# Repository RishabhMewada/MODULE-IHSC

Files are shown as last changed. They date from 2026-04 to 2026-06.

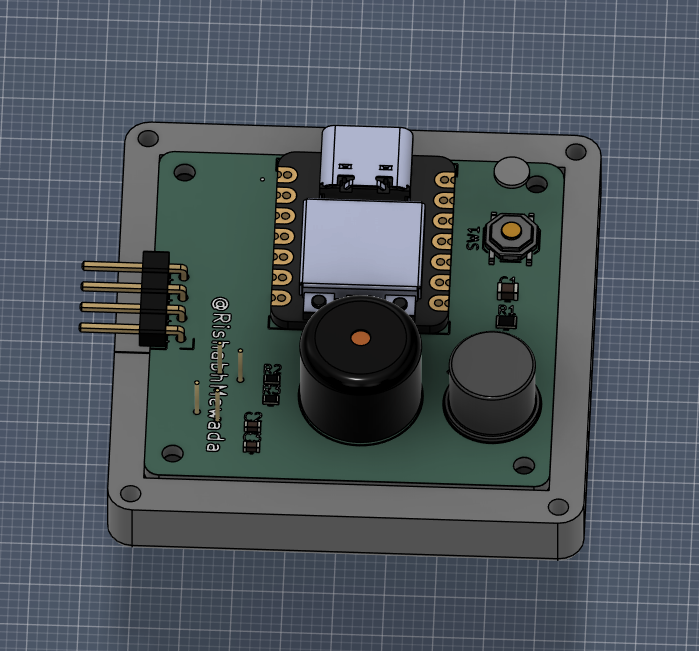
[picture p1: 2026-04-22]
Images/CAD-3.png

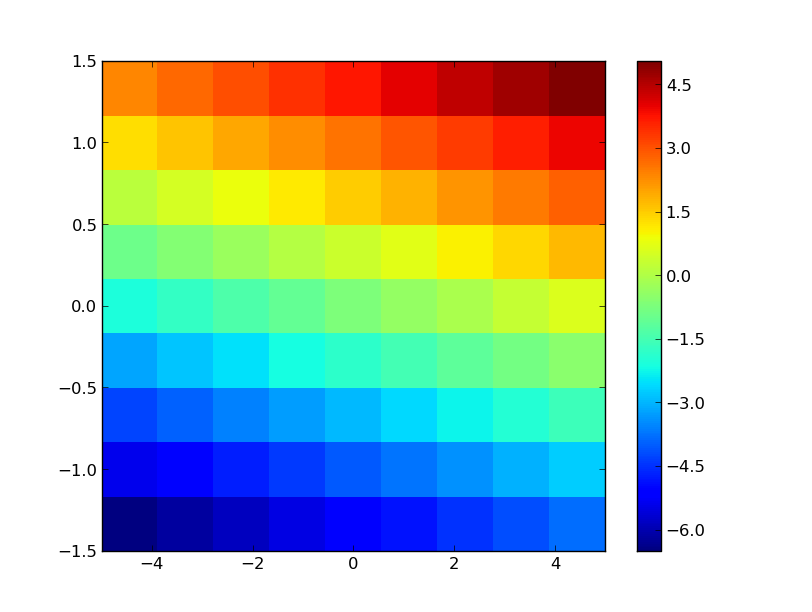
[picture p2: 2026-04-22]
Images/Rainbow heatmap.png

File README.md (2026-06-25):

# MODULE-IHSC
A thermal imaging module consisting of XIAO RP2040 &amp; MLX90640 for thermal camera and XIAO for the onboard processing 
which supports usb type c streaming and usb screen sharing extension via an 4 pin I2C extension

 <p align="center">
PCB-3D-FRONT
</p>

-------------------------------------------------------------------------------------------------
## Purpose 
The goal of this project was to design a low profile thermal camera module capable of streaming live
footage over to the screen via type c and I2C pins

things considerd in mind to make it happen
- PCB design
- CAD 
- Components
- Firmware modularization and easy modification
  
 <p align="center">
 Schematics
</p>

 <p align="center">

</p>

-------------------------------------------------------------------------------------------------
## Features

*Core Hardware*

- XIAO RP2040
- MLX90640  
- 4 Pin I2C horizontal pins 
- buzzer for beeping
- tactile switch
- transistor
 
-------------------------------------------------------------------------------------------------
## Transport & Connectivity

 - 4 Pin I2C horizontal pins 
- USB-C connection
-------------------------------------------------------------------------------------------------
## Hardware
The PCB is designed using KiCad (open-source) and the case using Fusion 360.

Specifications

- 2-layer PCB
- XIAO RP2040 Proccessing
- MLX90640  heat Camera
- I²C  4 pin connector
- 
All PCB source files are available in `/hardware/kicad`.

<p align="center">
  CAD-3
</p>

-------------------------------------------------------------------------------------------------

## Firmware

- Thermal Sensing camera

*Raw MLX90640 32×24 thermal array with 768 pixels, connected directly via I2C
with 110° wide field of view built into the camera
and have the abillity to measure −40 °C to +300 °C measurement range
Dual I2C bus architecture — sensor on I2C1 (GP6/GP7), display on I2C0 (GP4/GP5) to prevent bus conflicts*

- Rainbow Heatmap

*Full 7-stop rainbow colour mapping (violet → blue → cyan → green → yellow → orange → red)
Bicubic interpolation upscaling from 32×24 to full display resolution which will convert it into 
Real-time hotspot and coldspot crosshair overlays with temperature labels
Live temperature scale bar rendered on-screen*

<p align="center">
  Rainbow heatmap
</p>

- Dual Output System

*USB-CDC mode — binary frame stream over via a Type-C cable to a PC host viewer
I2C display mode — frames rendered directly onto an external OLED via the 4-pin PCB connector (SSD1306 128×64 or SH1107 128×128)
BOTH mode — simultaneous USB stream and I2C display output
Smart startup auto-detection: defaults to BOTH if display and USB host are both detected, I2C is used only if no PC is connected or USB if no display is found*

- Output Switching

*Short-press mode button cycles USB → I2C → BOTH → USB in real time
Long-press mode button saves current mode to flash (persists across reboots)
PC-side display_switch.py utility to switch modes remotely over USB without touching the device
Soft-reset trigger from PC so new mode activates immediately without unplugging* (made for future integration)

- PC Host Viewer (host_display.py)

*Live OpenCV window with rainbow heatmap whit support up to 30 fps
Bicubic interpolation for smooth upscaled display
Adjustable window scale factor
and it Cycle's through 5 colour maps: Rainbow, Inferno, Plasma, Bone, Jet
and the Temperature range lock/unlock (freeze min–max for consistent colour mapping)
and shows Hotspot and coldspot crosshairs with live °C labels and it has a 
Full-screen toggle
Live FPS counter and frame index overlay*

- PC Switch Utility (display_switch.py)

*Query current output mode from the device which 
Switchs to the output mode (USB / I2C / BOTH) via command line and
Scan the 4-pin I2C connector bus to detect connected display hardware and then
 the Live frame monitor — prints per-frame FPS, Tmin, Tmax, and checksum status and it also
Auto-detects RP2040 serial port (no --port flag needed in most cases)*

- Performance

*~30 fps live thermal stream at 32 Hz sensor refresh rate in the MLX90640 camera
-USB-CDC frame size: 1562 bytes per frame (~47 KB/s, well within USB bandwidth)
 and uses Binary framing protocol with magic header and checksum validation for data integrity
and Frame index tracking for dropped frame detection*

- Hardware Controls

*Power button (GP28): short press pauses/resumes streaming; long press enters light-sleep
Mode button (GP29): short press cycles output mode; long press saves mode to flash
Buzzer (GP27): distinct beep patterns for each event — power-on, mode switch (unique per mode), mode saved, sleep, and error*

- Buzzer Feedback

Single long beep on power-on
1 beep = USB mode selected
2 beeps = I2C display mode selected
3 beeps = BOTH mode / mode saved to flash
Double beep = entering sleep
5 rapid beeps = sensor not found (wiring error)

- Persistent Configuration

*Output mode saved to output_mode.json on the RP2040's onboard flash
Automatically restored on every reboot with no user intervention*

Firmware files are located in `/firmware`.

-------------------------------------------------------------------------------------------------
## Images

 <p align="center">
    PCB
</p>

 <p align="center">
    
</p>

<p align="center">
     
</p>

-------------------------------------------------------------------------------------------------
## BOM
The complete bill of materials (BOM), including purchase links, is available in  
`/hardware/bom.csv`.

Manufacturing & sourcing:
- PCB fabrication: **JLCPCB**
- Components (India): **Robu.in**
- Enclosure: Online 3D printing services (if needed)

  <p align="center">
   
</p>

## Bill of Materials

| Name | Quantity | Total Cost (USD) | Distributor | Link |
|---|---|---|---|---|
| PCB | 5 | $8.00 | JLCPCB | [Buy](https://cart.jlcpcb.com/shopcart/cart/) |
| Soldering Flux | 1 | $0.27 | Robu.in | [Buy](https://robu.in/product/noel-flux-soldering-paste-10g) |
| MLX90640 | 1 | $37.48 | Digikey.in | [Buy](https://www.digikey.in/en/products/detail/melexis-technologies-nv/MLX90640ESF-BAA-000-SP/8638465) |
| XIAO RP2040 | 1 | $6.41 | Robocraze.in | [Buy](https://robocraze.com/products/seeed-studio-xiao-rp2040-development-board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) |
| Buzzer (BZ1) | 1 | $0.15 | Robu.in | [Buy](https://robu.in/product/3v-active-electromagnetic-buzzer-pack-of-5) |
| 1×4 Pin Header (J1) | 1 | $0.14 | Robu.in | [Buy](https://robu.in/product/ds1022-22-1x10ruf1-a3-0-b6-0-c6-0-b-connfly-1x10-pin-2-54mm-pin-header-r-a-type-h2-0mm) |
| Low Profile Tactile Switch SMD | 1 | $0.11 | Robu.in | [Buy](https://robu.in/product/tsc008a1718a-bzcn-4x4x1-7mm-50ma-round-button-50gf-12v-smd-tactile-switches-rohs) |
| Resistor 4.7 kΩ 0603 (R2) | 2 | $0.11 | Robu.in | [Buy](https://robu.in/product/4-7k-ohm-1-4w-0603-surface-mount-chip-resistor-pack-of-100) |
| Resistor 1 kΩ 0805 (R1) | 1 | $0.11 | Robu.in | [Buy](https://robu.in/product/1k-ohm-1-4w-0805-surface-mount-chip-resistor-pack-of-10) |
| Capacitor 100 nF 0805 (C1) | 1 | $0.12 | Robu.in | [Buy](https://robu.in/product/cs2012x7r106m100nre-samwha-10v-10uf-x7r-%c2%b120-0805-multilayer-ceramic-capacitors-mlcc-smd-smt-rohs) |
| Capacitor 1 µF 0603 (C3) | 1 | $0.11 | Robu.in | [Buy](https://robu.in/product/1uf-1000nf-50v-capacitor-0603-smd-package-pack-of-20) |
| Capacitor 10 µF 0805 (C2) | 1 | $0.11 | Robu.in | [Buy](https://robu.in/product/100nf-0805-surface-mount-multilayer-ceramic-capacitor-pack-of-40) |
| 2N2219 Transistor | 1 | $ | link |
| **Total** | | **$77.81** | | |

please note that most of the parts are from indian suppliers !

*note there's also a transistor in the project (2N2219) but it's not available anywhere online for me that's why it's not included in the BOM with price and link

-------------------------------------------------------------------------------------------------
## License
This project is open-source hardware and software and is released under the **MIT License**.

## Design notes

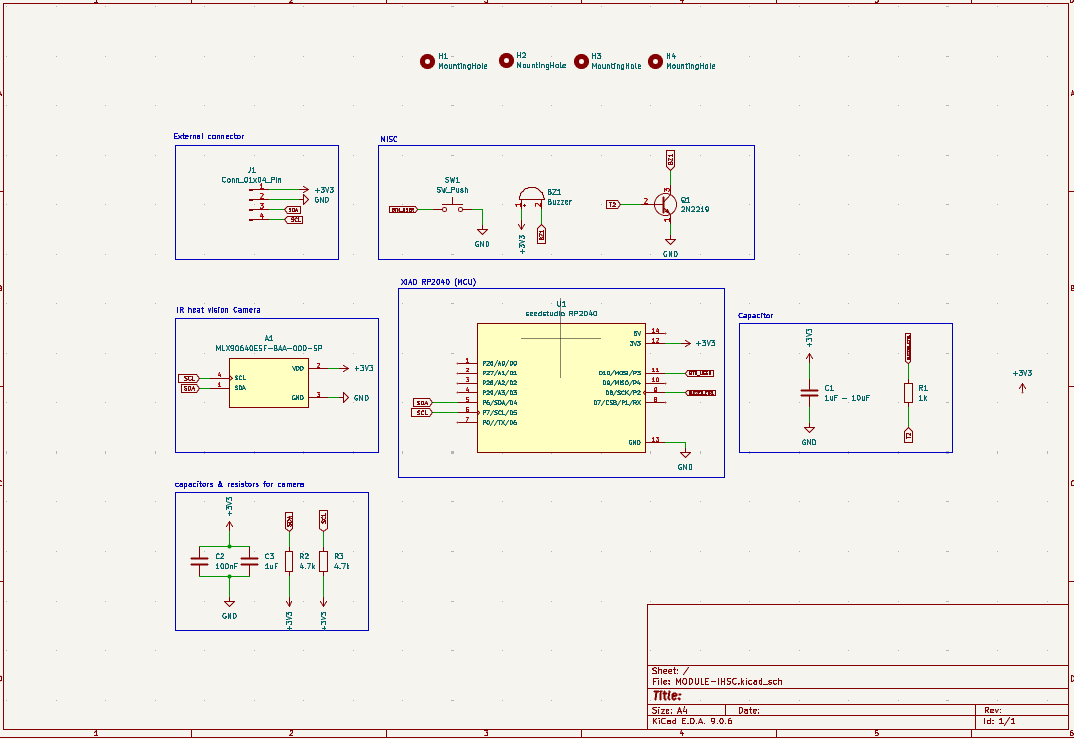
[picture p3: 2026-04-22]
Images/Schematics.png

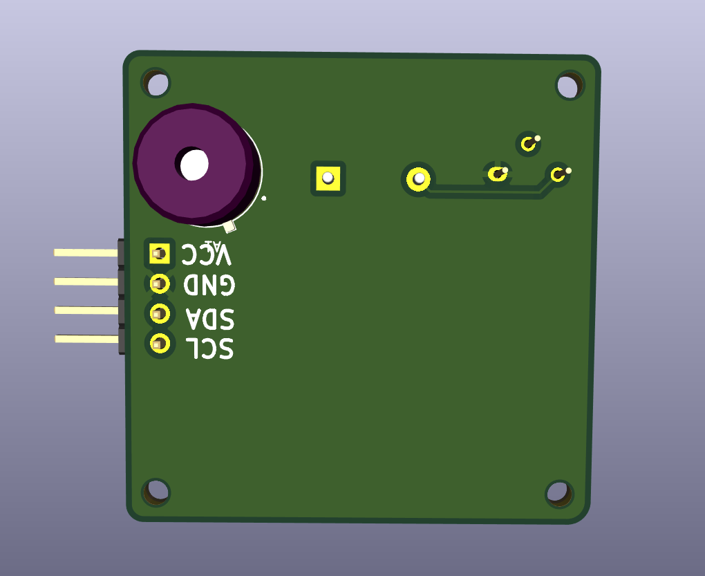
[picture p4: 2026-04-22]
Images/PCB-3D-BACK.png

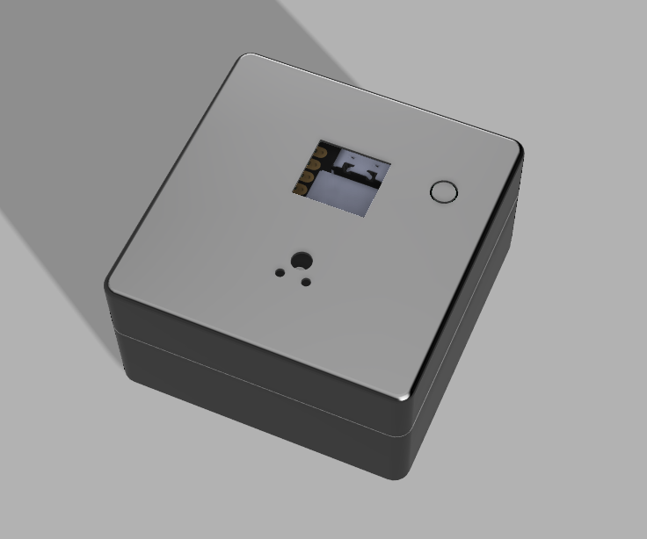
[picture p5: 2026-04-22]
Images/Render.png

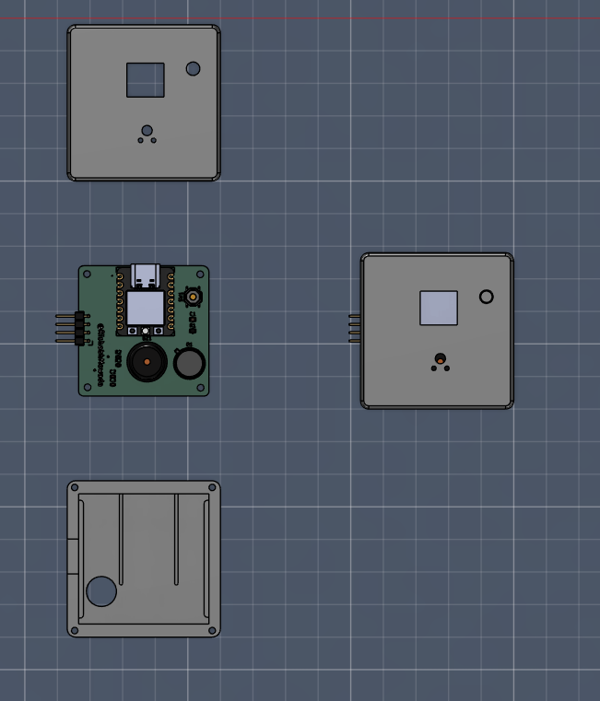
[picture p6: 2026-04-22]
Images/PCB-4.png

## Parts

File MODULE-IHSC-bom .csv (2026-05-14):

Name | Purpose | Quantity | Total Cost (USD) | Link | Distributor
hot air reflow gun | SMD | 1 | 23.98 | https://robu.in/product/yihua-8858-iv-portable-hot-air-station/ | Robu.in
PCB | pcb.its 8 dollars because i am also ordering pcb for my project side by side to reduce tax cost and shipping costs | 5 | 8.00 | https://cart.jlcpcb.com/shopcart/cart/ | JLPCB
soldering flux | flux | 1 | 0.27 | https://robu.in/product/noel-flux-soldering-paste-10g | Robu.in
MLX90640 | heat camera | 1 | 37.48 | https://www.digikey.in/en/products/detail/melexis-technologies-nv/MLX90640ESF-BAA-000-SP/8638465 | Digikey.in
XIAO RP2040 | MCU | 1 | 6.41 | https://robocraze.com/products/seeed-studio-xiao-rp2040-development-board?variant=47742255562976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 | Robocraze.in
Buzzer-BZ1 | beep beep. | 1 | 0.15 | https://robu.in/product/3v-active-electromagnetic-buzzer-pack-of-5 | Robu.in
1x4 pin header | would cut the 10 pin into 4 (J1) | 1 | 0.14 | https://robu.in/product/ds1022-22-1x10ruf1-a3-0-b6-0-c6-0-b-connfly-1x10-pin-2-54mm-pin-header-r-a-type-h2-0mm | Robu.in
low profile tactile switch SMD | switch. | 1 | 0.11 | https://robu.in/product/tsc008a1718a-bzcn-4x4x1-7mm-50ma-round-button-50gf-12v-smd-tactile-switches-rohs | Robu.in
Resistors | R2-4.7K Ohm | 2 | 0.11 | https://robu.in/product/4-7k-ohm-1-4w-0603-surface-mount-chip-resistor-pack-of-100 | Robu.in
Resistors | R1-1k Ohm | 1 | 0.11 | https://robu.in/product/1k-ohm-1-4w-0805-surface-mount-chip-resistor-pack-of-10 | Robu.in
capacitors | C1-100nF | 1 | 0.12 | https://robu.in/product/cs2012x7r106m100nre-samwha-10v-10uf-x7r-%c2%b120-0805-multilayer-ceramic-capacitors-mlcc-smd-smt-rohs | Robu.in
capacitors | C3-1uF | 1 | 0.11 | https://robu.in/product/1uf-1000nf-50v-capacitor-0603-smd-package-pack-of-20 | Robu.in
Capacitors | C2-10uF | 1 | 0.11 | https://robu.in/product/100nf-0805-surface-mount-multilayer-ceramic-capacitor-pack-of-40 | Robu.in

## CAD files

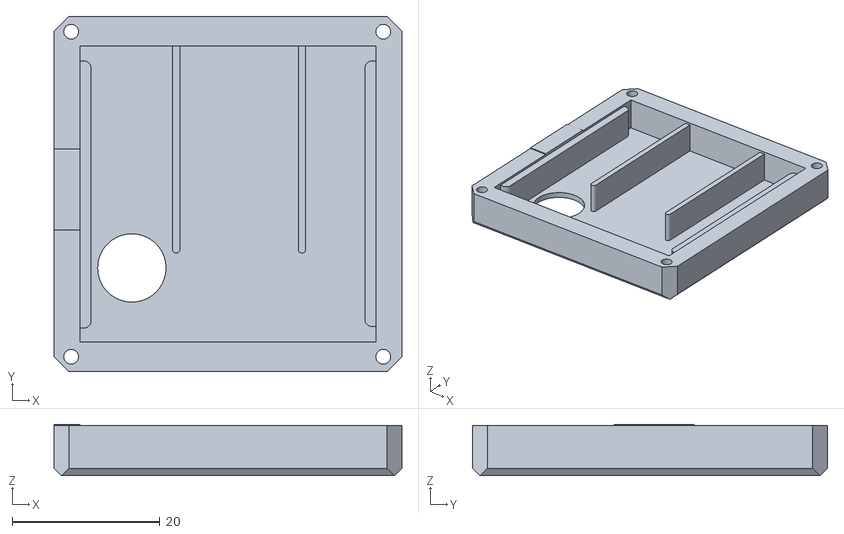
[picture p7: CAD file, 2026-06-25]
CAD MODELS/ IHSC-RD-BOTTOM-3DP.stl
47.0 x 48.0 x 6.94

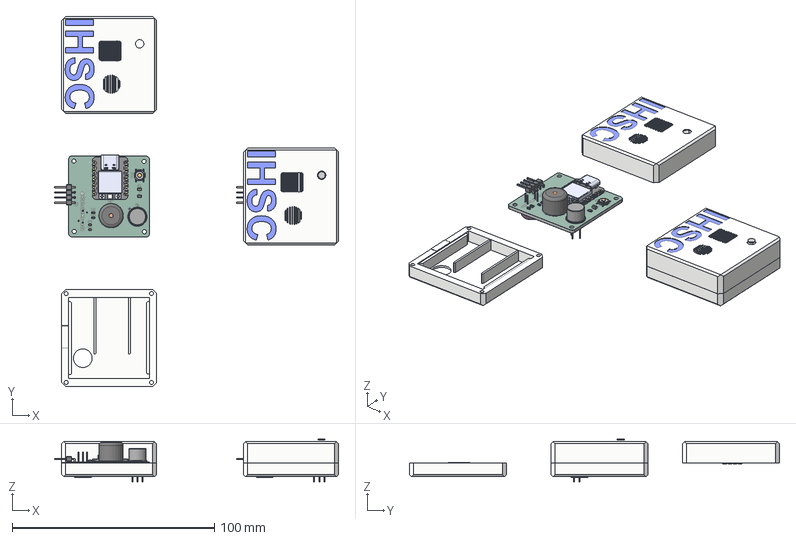
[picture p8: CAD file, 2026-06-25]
CAD MODELS/MODULE-IHSC-RD.step
140.5 x 183.0 x 21.1 mm
PinHeader_1x04_P2.54mm_Horizontal_1 x 2
C_0603_1608Metric x 4
C_0805_2012Metric x 2
R_0603_1608Metric x 4
PinHeader_1x04_P2.54mm_Horizontal x 2
R_0805_2012Metric x 2
TO-39-3 x 2
Buzzer_12x9.5RM7.6 x 2
SW_SPST_TL3342 x 2
MLX90640ESF-BAA-000-SP x 2
MODULE-IHSC_silkscreen x 2
MODULE-IHSC_silkscreen (1) x 2
MODULE-IHSC_soldermask x 2
MODULE-IHSC_soldermask (1) x 2
MODULE-IHSC_PCB x 2

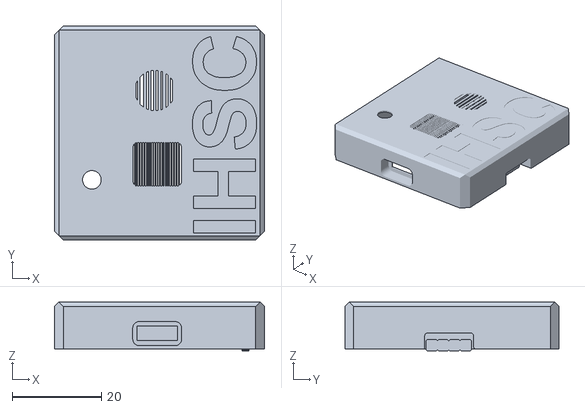
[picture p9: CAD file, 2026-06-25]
CAD MODELS/IHSC-RD-TOP-3DP.stl
47.0 x 48.0 x 11.0

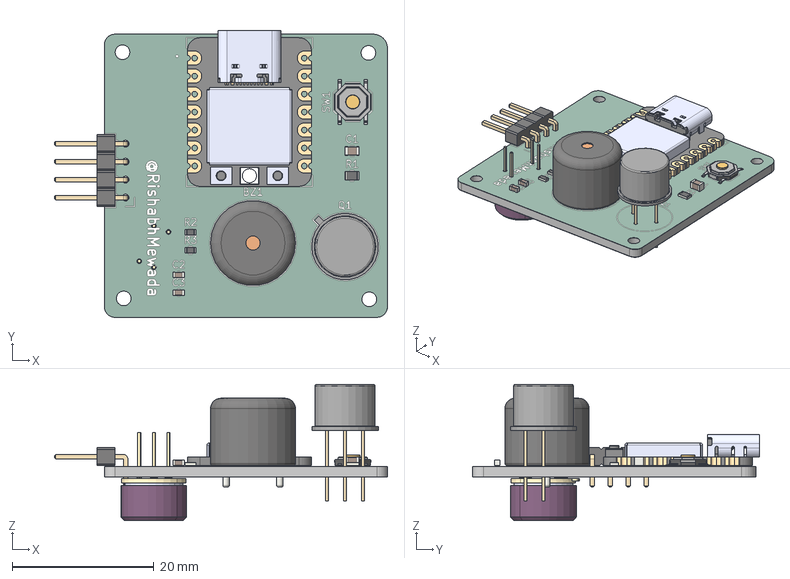
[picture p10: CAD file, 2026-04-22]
CAD MODELS/MODULE-IHSC.step
47.0 x 40.5 x 19.3 mm
C_0603_1608Metric x 2
C_0805_2012Metric
R_0603_1608Metric x 2
PinHeader_1x04_P2.54mm_Horizontal
R_0805_2012Metric
TO-39-3
Buzzer_12x9.5RM7.6
SW_SPST_TL3342
MLX90640ESF-BAA-000-SP
MODULE-IHSC_silkscreen x 2
MODULE-IHSC_soldermask x 2
MODULE-IHSC_PCB

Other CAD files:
CAD MODELS/MODULE-IHSC-RD.f3z
CAD MODELS/MODULE-IHSC-RD.stl

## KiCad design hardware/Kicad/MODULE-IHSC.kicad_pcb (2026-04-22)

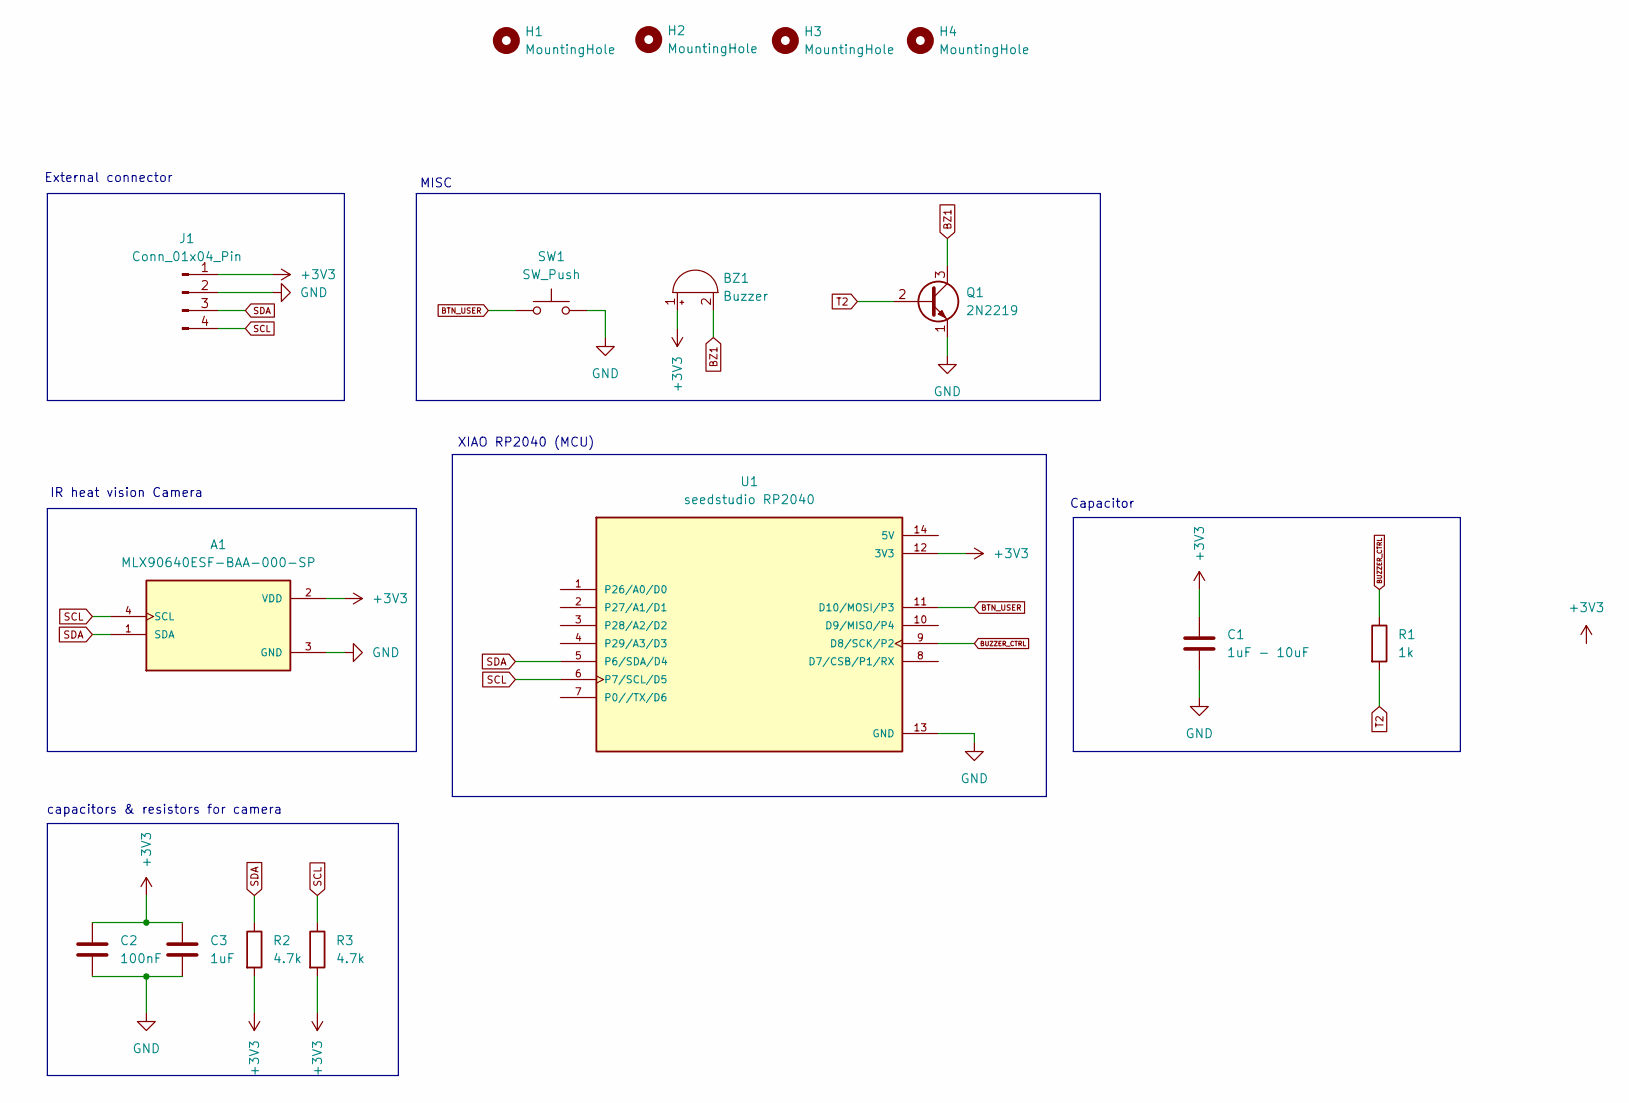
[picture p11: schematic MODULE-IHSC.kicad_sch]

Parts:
A1: MLX90640ESF-BAA-000-SP; TO292P930H600-4
BZ1: Buzzer; Buzzer_12x9.5RM7.6
C1: 1uF - 10uF; C_0805_2012Metric
C2: 100nF; C_0603_1608Metric
C3: 1uF; C_0603_1608Metric
H1, H2, H3, H4: MountingHole; MountingHole_2.1mm
J1: Conn_01x04_Pin; PinHeader_1x04_P2.54mm_Horizontal
Q1: 2N2219; TO-39-3
R1: 1k; R_0805_2012Metric
R2, R3: 4.7k; R_0603_1608Metric
SW1: SW_Push; SW_SPST_TL3342
U1: seedstudio RP2040; MODULE_102010428; DigiKey_Part_Number 1597-102010428-ND

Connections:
SCL: A1.4 (SCL), J1.4, R3.1, U1.6 (P7/SCL/D5)
+3V3: A1.2 (VDD), BZ1.1 (+), C1.1, C2.1, C3.1, J1.1, R2.2, R3.2, U1.12 (3V3)
BTN_USER: SW1.1, U1.11 (D10/MOSI/P3)
BUZZER_CTRL: R1.1, U1.9 (D8/SCK/P2)
BZ1: BZ1.2 (-), Q1.3 (C)
GND: A1.3 (GND), C1.2, C2.2, C3.2, J1.2, Q1.1 (E), SW1.2, U1.13 (GND)
SDA: A1.1 (SDA), J1.3, R2.1, U1.5 (P6/SDA/D4)
T2: Q1.2 (B), R1.2

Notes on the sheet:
MISC
XIAO RP2040 (MCU)
IR heat vision Camera
Capacitor
capacitors & resistors for camera
External connector

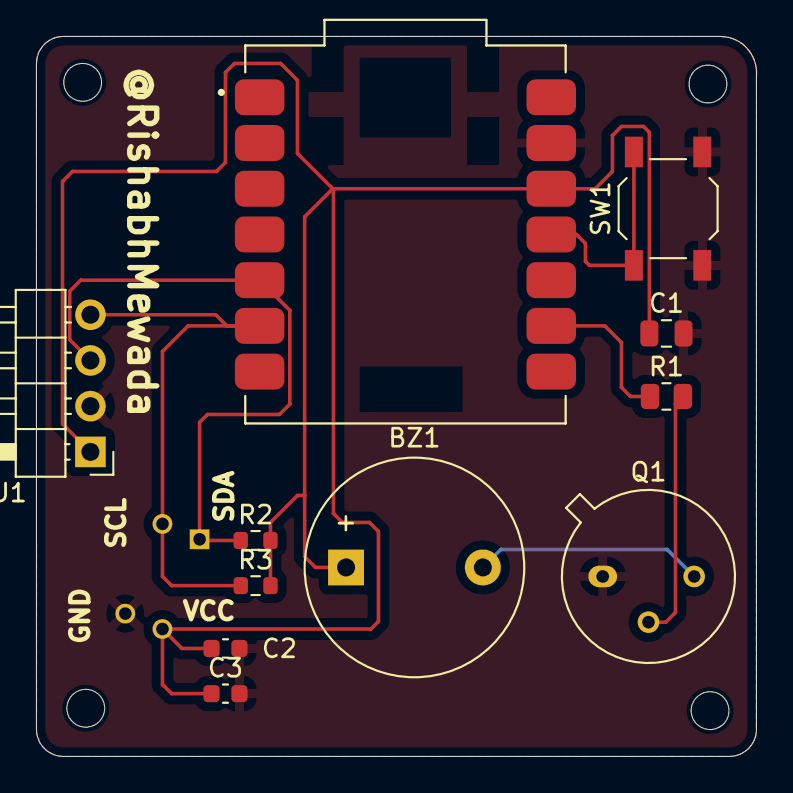
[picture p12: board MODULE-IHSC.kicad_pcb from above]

Board: 2 copper layers, 40.0 x 40.0 mm, 16 parts (1 on the bottom side), 8 nets.

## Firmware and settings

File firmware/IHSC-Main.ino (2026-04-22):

"""
=============================================================
  Thermal Camera — XIAO RP2040 + MLX90640 (110° FOV)
  Rainbow Heatmap  |  Dual Output  |  ~30 FPS
=============================================================

Hardware connections
--------------------
Raw MLX90640 chip (I2C1)  →  XIAO RP2040
  Pin 1 (VDD)  →  3V3
  Pin 2 (VSS)  →  GND
  Pin 3 (SDA)  →  GP6   (I2C1 SDA)
  Pin 4 (SCL)  →  GP7   (I2C1 SCL)

  REQUIRED external components (not on bare chip):
    4.7 kΩ resistor between GP6 (SDA) and 3V3  ← I2C pull-up
    4.7 kΩ resistor between GP7 (SCL) and 3V3  ← I2C pull-up
    100 nF ceramic capacitor between VDD and GND (place right at chip pins)

Buzzer    →  GP27  + GND  (active-high by default)
Power btn →  GP28  + GND  (internal pull-up)
Mode btn  →  GP29  + GND  (internal pull-up)

4-pin PCB output connector (I2C0 — second I2C bus)
----------------------------------------------------
  Pin 1  →  3V3          (power for external display)
  Pin 2  →  GND          (common ground)
  Pin 3  →  GP4  (SDA0)  (I2C data  → external display SDA)
  Pin 4  →  GP5  (SCL0)  (I2C clock → external display SCL)

  The RP2040 acts as I2C0 MASTER on this bus.
  The external display (e.g. SSD1306 OLED, SH1107, ST7789 via I2C)
  is the SLAVE. Frames are written to the display controller directly.

  Supported external display types (set EXT_DISPLAY_TYPE below):
    "SSD1306"  — 128×64 monochrome OLED  (I2C addr 0x3C or 0x3D)
    "SH1107"   — 128×128 monochrome OLED (I2C addr 0x3C)
    "NONE"     — 4-pin connector active but no rendering (raw I2C)

Output modes
------------
  MODE_USB  (0) : frames streamed over USB-CDC (Type-C → PC host_display.py)
  MODE_I2C  (1) : frames rendered on external I2C display (4-pin connector)
  MODE_BOTH (2) : USB-CDC stream AND I2C display simultaneously

Mode switching
--------------
  Short-press MODE_BTN  → cycle  USB → I2C → BOTH → USB …
  Long-press  MODE_BTN  → save current mode to flash (survives reboot)
  Short-press POWER_BTN → toggle streaming on/off
  Long-press  POWER_BTN → enter light-sleep (low power)

Startup mode priority
---------------------
  1. Saved mode in flash (output_mode.json) — if previously saved
  2. I2C display mode if an I2C display is detected on the 4-pin bus
  3. USB-CDC mode if a PC host is connected
  4. I2C mode as fallback (standalone use)

Buzzer feedback
---------------
  Power-on           : 1 long beep (200 ms)
  USB mode           : 1 medium beep
  I2C display mode   : 2 short beeps
  BOTH mode          : 3 short beeps
  Mode saved         : 3 short beeps
  Long-press sleep   : double beep
  No sensor error    : 5 rapid beeps

Protocol (USB-CDC binary, little-endian)
-----------------------------------------
  Offset  Size  Type      Field
  ------  ----  --------  --------------------------------
  0       4     uint32    Magic : 0xDEADBEEF
  4       2     uint16    Width  = 32
  6       2     uint16    Height = 24
  8       4     uint32    Frame index
  12      1     uint8     Output mode (0=USB 1=I2C 2=BOTH)
  13      3     uint8[3]  Reserved = 0x000000
  16      4     int32     T_min milli-°C
  20      4     int32     T_max milli-°C
  24      1536  uint16[]  Pixels: value = (T_°C + 40) × 100
  1560    2     uint16    Checksum (sum of pixel bytes & 0xFFFF)

Total = 1562 bytes per frame
=============================================================
"""

import time
import struct
import sys
import ustruct
import machine
import json
from machine import I2C, Pin

# ──────────────────────────────────────────────
#  Pin configuration
# ──────────────────────────────────────────────
# MLX90640 — I2C bus 1
I2C1_SDA_PIN = 6
I2C1_SCL_PIN = 7
I2C1_FREQ    = 400_000        # 400 kHz

# External display — I2C bus 0 (4-pin PCB connector)
I2C0_SDA_PIN = 4              # Pin 3 on connector
I2C0_SCL_PIN = 5              # Pin 4 on connector
I2C0_FREQ    = 400_000        # 400 kHz (reduce to 100_000 for long wires)

BUZZER_PIN         = 27
BUZZER_ACTIVE_HIGH = True

POWER_BTN_PIN = 28
MODE_BTN_PIN  = 29

# External display type — set to match your hardware
# Options: "SSD1306"  "SH1107"  "NONE"
EXT_DISPLAY_TYPE = "SSD1306"

# I2C addresses to scan for on the 4-pin bus
DISPLAY_ADDRS = {
    "SSD1306": [0x3C, 0x3D],
    "SH1107":  [0x3C, 0x3D],
    "NONE":    [],
}

# ──────────────────────────────────────────────
#  MLX90640
# ──────────────────────────────────────────────
MLX_ADDR     = 0x33
FRAME_WIDTH  = 32
FRAME_HEIGHT = 24
N_PIXELS     = FRAME_WIDTH * FRAME_HEIGHT
MLX_RATE_REG = 0b111          # 32 Hz

# ──────────────────────────────────────────────
#  Output modes
# ──────────────────────────────────────────────
MODE_USB  = 0
MODE_I2C  = 1
MODE_BOTH = 2
MODE_NAMES = {
    MODE_USB:  "USB-CDC",
    MODE_I2C:  "I2C-DISPLAY",
    MODE_BOTH: "BOTH",
}

CONFIG_FILE = "output_mode.json"

# ──────────────────────────────────────────────
#  Protocol (USB-CDC)
# ──────────────────────────────────────────────
MAGIC       = 0xDEADBEEF
HEADER_FMT  = "<IHHIBxxxii"
HEADER_SIZE = struct.calcsize(HEADER_FMT)   # 24 bytes
PIXEL_BYTES = N_PIXELS * 2                  # 1536 bytes
FRAME_SIZE  = HEADER_SIZE + PIXEL_BYTES + 2 # 1562 bytes


# ══════════════════════════════════════════════
#  Rainbow colour mapping  (7 colour stops)
#  Maps 0.0–1.0 → (R, G, B) 0–255
# ══════════════════════════════════════════════
# Colour stops: violet → blue → cyan → green → yellow → orange → red
_RAINBOW = [
    (0.00, (148,   0, 211)),   # violet
    (0.17, (  0,   0, 255)),   # blue
    (0.33, (  0, 255, 255)),   # cyan
    (0.50, (  0, 255,   0)),   # green
    (0.67, (255, 255,   0)),   # yellow
    (0.83, (255, 165,   0)),   # orange
    (1.00, (255,   0,   0)),   # red
]

def rainbow_rgb(t):
    """t in [0.0, 1.0] → (r, g, b) tuple 0-255."""
    t = max(0.0, min(1.0, t))
    for i in range(len(_RAINBOW) - 1):
        t0, c0 = _RAINBOW[i]
        t1, c1 = _RAINBOW[i + 1]
        if t0 <= t <= t1:
            f = (t - t0) / (t1 - t0)
            return (
                int(c0[0] + f * (c1[0] - c0[0])),
                int(c0[1] + f * (c1[1] - c0[1])),
                int(c0[2] + f * (c1[2] - c0[2])),
            )
    return _RAINBOW[-1][1]

def rainbow_gray(t):
    """Convert rainbow RGB → 8-bit grey (for monochrome displays)."""
    r, g, b = rainbow_rgb(t)
    return (r * 299 + g * 587 + b * 114) // 1000


# ══════════════════════════════════════════════
#  Flash config helpers
# ══════════════════════════════════════════════
def load_saved_mode():
    try:
        with open(CONFIG_FILE, "r") as f:
            cfg = json.load(f)
        m = int(cfg.get("mode", -1))
        if m in (MODE_USB, MODE_I2C, MODE_BOTH):
            print(f"[CFG] Loaded saved mode: {MODE_NAMES[m]}")
            return m
    except Exception:
        pass
    return None


def save_mode_to_flash(mode):
    try:
        with open(CONFIG_FILE, "w") as f:
            json.dump({"mode": mode}, f)
        print(f"[CFG] Mode saved: {MODE_NAMES[mode]}")
    except Exception as e:
        print(f"[CFG] Save failed: {e}")


# ══════════════════════════════════════════════
#  USB presence check
# ══════════════════════════════════════════════
def usb_enumerated():
    try:
        sys.stdout.buffer.write(b"")
        return True
    except Exception:
        return False


# ══════════════════════════════════════════════
#  MLX90640 driver
# ══════════════════════════════════════════════
class MLX90640:
    _REG_STATUS  = 0x8000
    _REG_CTRL1   = 0x800D
    _RAM_BASE    = 0x0400
    _EEPROM_BASE = 0x2400

    def __init__(self, i2c, addr=MLX_ADDR):
        self.i2c     = i2c
        self.addr    = addr
        self._buf2   = bytearray(2)
        self._eeprom = None
        self._params = {}
        self._load_eeprom()
        self._extract_params()
        self._set_refresh_rate(MLX_RATE_REG)

    def _read_reg(self, reg, n_words):
        self._buf2[0] = reg >> 8
        self._buf2[1] = reg & 0xFF
        self.i2c.writeto(self.addr, self._buf2)
        raw = self.i2c.readfrom(self.addr, n_words * 2)
        return [ustruct.unpack_from(">H", raw, i * 2)[0] for i in range(n_words)]

    def _write_reg(self, reg, value):
        buf = bytearray(4)
        buf[0] = reg >> 8;   buf[1] = reg & 0xFF
        buf[2] = value >> 8; buf[3] = value & 0xFF
        self.i2c.writeto(self.addr, buf)

    def _load_eeprom(self):
        self._eeprom = self._read_reg(self._EEPROM_BASE, 832)

    def _set_refresh_rate(self, rate_bits):
        ctrl = self._read_reg(self._REG_CTRL1, 1)[0]
        ctrl = (ctrl & ~0x0380) | ((rate_bits & 0x07) << 7)
        self._write_reg(self._REG_CTRL1, ctrl)

    def _extract_params(self):
        ee = self._eeprom
        p  = self._params

        p['K_Vdd'] = ee[51] >> 8
        if p['K_Vdd'] > 127: p['K_Vdd'] -= 256
        p['K_Vdd'] *= 32
        p['Vdd25']  = ((ee[51] & 0x00FF) - 256) * 32 - 8192

        p['KT_PTAT']  = ee[50] & 0x03FF
        if p['KT_PTAT'] > 511: p['KT_PTAT'] -= 1024
        p['KT_PTAT'] /= 8.0
        p['V25']       = 6144
        p['alphaPTAT'] = (ee[16] >> 12) / 4.0 + 8.0

        p['gain'] = ee[48]
        if p['gain'] > 32767: p['gain'] -= 65536

        ctrl1 = self._read_reg(self._REG_CTRL1, 1)[0]
        p['res_corr'] = 3 - ((ctrl1 >> 10) & 0x03)

        p['emissivity']  = (ee[56] & 0x1FFF) / 32768.0
        p['alpha_scale'] = ((ee[32] >> 12) & 0x0F) + 30

        p['TGC'] = ee[60] & 0x00FF
        if p['TGC'] > 127: p['TGC'] -= 256
        p['TGC'] /= 32.0

        p['KsTa'] = (ee[60] >> 8) & 0x00FF
        if p['KsTa'] > 127: p['KsTa'] -= 256
        p['KsTa'] /= 8192.0

        p['alphaCPsubpage0'] = (ee[58] & 0x03FF) / (2 ** (p['alpha_scale'] + 27.0))
        ratio = (ee[58] >> 10) & 0x3F
        if ratio > 31: ratio -= 64
        p['alphaCPsubpage1'] = p['alphaCPsubpage0'] * (1 + ratio / 128.0)

        p['offsetCPsubpage0'] = ee[58] & 0x0FFF
        if p['offsetCPsubpage0'] > 2047: p['offsetCPsubpage0'] -= 4096
        p['offsetCPsubpage1'] = (ee[59] >> 10) & 0x3F
        if p['offsetCPsubpage1'] > 31: p['offsetCPsubpage1'] -= 64
        p['offsetCPsubpage1'] += p['offsetCPsubpage0']

        p['KV_CP'] = (ee[59] >> 8) & 0x0F
        if p['KV_CP'] > 7: p['KV_CP'] -= 16
        p['KV_CP'] /= 4.0

        p['KTa_CP'] = ee[59] & 0xFF
        if p['KTa_CP'] > 127: p['KTa_CP'] -= 256
        p['KTa_CP'] /= 8192.0

        print("[MLX90640] Parameters OK")

    def _wait_data_ready(self, subpage, timeout_ms=200):
        t0 = time.ticks_ms()
        while True:
            status = self._read_reg(self._REG_STATUS, 1)[0]
            if (status & 0x0008) and ((status & 0x0001) == subpage):
                self._write_reg(self._REG_STATUS, status & ~0x0008)
                return True
            if time.ticks_diff(time.ticks_ms(), t0) > timeout_ms:
                return False

    def get_frame(self):
        temps = [0.0] * N_PIXELS
        for subpage in (0, 1):
            if not self._wait_data_ready(subpage, timeout_ms=80):
                continue
            raw = self._read_reg(self._RAM_BASE, 832)
            self._compensate_subpage(raw, subpage, temps)
        return temps

    def _compensate_subpage(self, raw, subpage, out):
        p  = self._params
        ee = self._eeprom

        Vdd_raw = raw[810 + subpage]
        if Vdd_raw > 32767: Vdd_raw -= 65536
        Vdd = (Vdd_raw - p['Vdd25']) / p['K_Vdd'] + 3.3

        VPTAT_raw = raw[800]
        if VPTAT_raw > 32767: VPTAT_raw -= 65536
        VPTAT = VPTAT_raw / (2 ** p['res_corr'])

        VBE_raw = raw[768]
        if VBE_raw > 32767: VBE_raw -= 65536
        VBE = VBE_raw * 0.000152587890625

        VPTAT_art = (VPTAT / (VPTAT * p['alphaPTAT'] + VBE)) * 262144
        Ta = (VPTAT_art / p['gain'] - p['V25']) / p['KT_PTAT'] + 25.0

        gain_ram = raw[778]
        if gain_ram > 32767: gain_ram -= 65536
        gain = p['gain'] / gain_ram

        VCP = raw[808 + subpage]
        if VCP > 32767: VCP -= 65536
        offsetCP = (p['offsetCPsubpage0'] if subpage == 0
                    else p['offsetCPsubpage1'])
        VCP  = VCP * gain
        VCP -= (offsetCP * (1 + p['KTa_CP'] * (Ta - 25.0)) *
                (1 + p['KV_CP'] * (Vdd - 3.3)))

        emissivity = p['emissivity']
        TGC        = p['TGC']
        KsTa       = p['KsTa']

        for pixel in range(N_PIXELS):
            row = pixel // FRAME_WIDTH
            col = pixel % FRAME_WIDTH
            if ((row + col + subpage) & 1) != 0:
                continue

            ir = raw[pixel]
            if ir > 32767: ir -= 65536
            ir *= gain

            pix_os_ref = ee[64 + pixel] & 0x000F
            if pix_os_ref > 7: pix_os_ref -= 16
            pix_os_ref <<= 3

            row_val = (ee[24 + row // 4] >> ((row % 4) * 4)) & 0x0F
            if row_val > 7: row_val -= 16

            col_val = (ee[32 + col // 4] >> ((col % 4) * 4)) & 0x0F
            if col_val > 7: col_val -= 16

            Offset  = pix_os_ref + row_val + col_val
            Offset *= (1 + ((ee[56 + pixel // 16] >>
                             ((pixel % 16) * 2)) & 0x03) * 0.0625 * (Ta - 25.0))
            Offset *= (1 + p['KV_CP'] * (Vdd - 3.3))
            ir -= Offset

            alpha_pix = (ee[64 + pixel] >> 4) & 0x0FFF
            if alpha_pix > 2047: alpha_pix -= 4096
            alpha_pix /= 2 ** p['alpha_scale']

            Sx  = alpha_pix * ((ir - TGC * VCP) / emissivity)
            To  = (Sx / (alpha_pix * (1 + KsTa * (Ta - 25.0))) +
                   (Ta + 273.15) ** 4) ** 0.25 - 273.15
            out[pixel] = To


# ══════════════════════════════════════════════
#  SSD1306 / SH1107 I2C display driver
#  128×64 monochrome — renders rainbow heatmap
#  as a greyscale-dithered thermal image
# ══════════════════════════════════════════════
class I2CDisplay:
    """
    Minimal I2C display driver supporting SSD1306 (128×64) and
    SH1107 (128×128). Renders the 32×24 thermal frame as a
    rainbow-to-greyscale heatmap with a temperature scale bar
    and min/max markers.

    The 32×24 sensor image is upscaled to fit the display:
      SSD1306 128×64  → 4×2 pixels per thermal pixel  (128×48 image area)
      SH1107  128×128 → 4×5 pixels per thermal pixel  (128×120 image area)
    """

    # SSD1306 commands
    _SSD_INIT = bytes([
        0x00,          # command stream
        0xAE,          # display off
        0xD5, 0x80,    # clock div
        0xA8, 0x3F,    # mux ratio 64
        0xD3, 0x00,    # display offset 0
        0x40,          # start line 0
        0x8D, 0x14,    # charge pump on
        0x20, 0x00,    # horizontal addressing
        0xA1,          # seg remap
        0xC8,          # com scan reversed
        0xDA, 0x12,    # com pins
        0x81, 0xCF,    # contrast
        0xD9, 0xF1,    # precharge
        0xDB, 0x40,    # vcomh
        0xA4,          # entire display on (RAM)
        0xA6,          # normal (not inverted)
        0xAF,          # display ON
    ])

    def __init__(self, i2c, addr=0x3C, display_type="SSD1306"):
        self._i2c   = i2c
        self._addr  = addr
        self._dtype = display_type.upper()

        if self._dtype in ("SSD1306",):
            self._w, self._h = 128, 64
        elif self._dtype == "SH1107":
            self._w, self._h = 128, 128
        else:
            self._w, self._h = 128, 64

        # Framebuffer: 1 bit per pixel, pages of 8 rows
        self._pages = self._h // 8
        self._buf   = bytearray(self._w * self._pages)
        self._init_display()

        # Upscale factors
        self._px = self._w // FRAME_WIDTH          # 4 for 128-wide
        self._py = (self._h - 16) // FRAME_HEIGHT  # leave 16 px for status bar

        print(f"[DISP] {self._dtype} {self._w}×{self._h} @ {hex(addr)} ready  "
              f"cell={self._px}×{self._py}px")

    def _cmd(self, data):
        self._i2c.writeto(self._addr, b'\x00' + bytes(data))

    def _init_display(self):
        if self._dtype == "SSD1306":
            self._i2c.writeto(self._addr, self._SSD_INIT)
        elif self._dtype == "SH1107":
            self._cmd([0xAE, 0xDC, 0x00, 0x81, 0x4F,
                       0x20, 0xA0, 0xC8, 0xA8, 0x7F,
                       0xD3, 0x60, 0xD5, 0x51, 0xD9,
                       0x22, 0xDB, 0x35, 0xB0, 0xDA,
                       0x12, 0xA4, 0xA6, 0xAF])

    # ── pixel helpers ─────────────────────────
    def _set_pixel(self, x, y, on=True):
        if 0 <= x < self._w and 0 <= y < self._h:
            page = y // 8
            bit  = y % 8
            idx  = page * self._w + x
            if on:
                self._buf[idx] |= (1 << bit)
            else:
                self._buf[idx] &= ~(1 << bit)

    def _fill_rect(self, x, y, w, h, on=True):
        for dy in range(h):
            for dx in range(w):
                self._set_pixel(x + dx, y + dy, on)

    def _draw_text3x5(self, x, y, text, on=True):
        """Tiny 3×5 font for numbers/labels — built-in, no font file needed."""
        FONT = {
            '0': [0b111,0b101,0b101,0b101,0b111],
            '1': [0b010,0b110,0b010,0b010,0b111],
            '2': [0b111,0b001,0b111,0b100,0b111],
            '3': [0b111,0b001,0b111,0b001,0b111],
            '4': [0b101,0b101,0b111,0b001,0b001],
            '5': [0b111,0b100,0b111,0b001,0b111],
            '6': [0b111,0b100,0b111,0b101,0b111],
            '7': [0b111,0b001,0b001,0b001,0b001],
            '8': [0b111,0b101,0b111,0b101,0b111],
            '9': [0b111,0b101,0b111,0b001,0b111],
            '.': [0b000,0b000,0b000,0b000,0b010],
            '-': [0b000,0b000,0b111,0b000,0b000],
            'C': [0b111,0b100,0b100,0b100,0b111],
            ' ': [0b000,0b000,0b000,0b000,0b000],
            'U': [0b101,0b101,0b101,0b101,0b111],
            'I': [0b111,0b010,0b010,0b010,0b111],
            'B': [0b110,0b101,0b110,0b101,0b110],
        }
        cx = x
        for ch in text:
            rows = FONT.get(ch, FONT[' '])
            for row_i, row_bits in enumerate(rows):
                for col_i in range(3):
                    if row_bits & (1 << (2 - col_i)):
                        self._set_pixel(cx + col_i, y + row_i, on)
            cx += 4   # 3 px glyph + 1 px gap

    # ── main render ───────────────────────────
    def show_frame(self, temps, t_min, t_max, mode):
        """Render a complete thermal frame onto the display."""
        self._buf = bytearray(self._w * self._pages)  # clear

        span = max(t_max - t_min, 0.5)
        px   = self._px
        py   = self._py

        # ── Thermal image (upscaled) ──────────
        for row in range(FRAME_HEIGHT):
            for col in range(FRAME_WIDTH):
                t    = temps[row * FRAME_WIDTH + col]
                norm = (t - t_min) / span
                gray = rainbow_gray(norm)   # 0–255
                # Ordered dithering (2×2 Bayer) for pseudo-greyscale on 1bpp
                threshold = 128
                bayer_2x2 = [[64, 192], [192, 64]]
                on = gray > bayer_2x2[row % 2][col % 2]
                x0 = col * px
                y0 = row * py
                self._fill_rect(x0, y0, px, py, on)

        # ── Scale bar (right 8 px) ────────────
        bar_x = self._w - 8
        bar_h = FRAME_HEIGHT * py
        for y in range(bar_h):
            norm = 1.0 - y / bar_h
            gray = rainbow_gray(norm)
            bayer = [64, 192]
            on = gray > bayer[y % 2]
            for bx in range(6):
                self._set_pixel(bar_x + bx, y, on)

        # ── Status bar (bottom 16 px) ─────────
        status_y = FRAME_HEIGHT * py + 2

        t_min_str = f"{t_min:.1f}C"
        t_max_str = f"{t_max:.1f}C"
        mode_str  = "U" if mode == MODE_USB else ("I" if mode == MODE_I2C else "B")

        self._draw_text3x5(0,  status_y, t_min_str)
        self._draw_text3x5(44, status_y, t_max_str)
        self._draw_text3x5(self._w - 8, status_y, mode_str)

        # ── Flush to display ──────────────────
        self._flush()

    def show_message(self, line1, line2=""):
        """Show a two-line text message (startup / error screens)."""
        self._buf = bytearray(self._w * self._pages)
        self._draw_text3x5(0,  4, line1[:20])
        self._draw_text3x5(0, 12, line2[:20])
        self._flush()

    def _flush(self):
        """Send framebuffer to display over I2C."""
        if self._dtype == "SSD1306":
            self._cmd([0x21, 0, 127,   # column address 0–127
                       0x22, 0, self._pages - 1])  # page address
        # Write data in chunks (I2C buffer limit ~256 bytes)
        chunk = 16   # 16 columns per write
        for start in range(0, len(self._buf), chunk):
            payload = b'\x40' + bytes(self._buf[start:start + chunk])
            self._i2c.writeto(self._addr, payload)


# ══════════════════════════════════════════════
#  Buzzer
# ══════════════════════════════════════════════
class Buzzer:
    def __init__(self, pin, active_high=True):
        self._pin = Pin(pin, Pin.OUT)
        self._ah  = active_high
        self._off()

    def _on(self):  self._pin.value(1 if self._ah else 0)
    def _off(self): self._pin.value(0 if self._ah else 1)

    def beep(self, ms=150):
        self._on(); time.sleep_ms(ms); self._off()

    def double_beep(self):
        self.beep(100); time.sleep_ms(80); self.beep(100)

    def triple_beep(self):
        for _ in range(3):
            self.beep(60); time.sleep_ms(60)

    def mode_beep(self, mode):
        if mode == MODE_USB:
            self.beep(180)                               # 1 medium
        elif mode == MODE_I2C:
            self.beep(80); time.sleep_ms(60); self.beep(80)  # 2 short
        elif mode == MODE_BOTH:
            self.triple_beep()                           # 3 short
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
if __name__ == "__main__":
    main()

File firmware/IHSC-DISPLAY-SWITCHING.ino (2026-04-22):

"""
=============================================================
  display_switch.py — Output Mode Switcher & Monitor
  PC-side utility for the XIAO RP2040 Thermal Camera
=============================================================

OVERVIEW
--------
This script lets you switch the RP2040's output port between:
  • USB-CDC   — frames streamed to PC over Type-C cable
  • I2C-DISP  — frames rendered on 4-pin I2C connector display
  • BOTH       — USB-CDC stream AND I2C display simultaneously

Switching is done by writing a 1-byte command into the saved
config file (output_mode.json) on the RP2040's flash via the
USB-CDC serial connection. The RP2040 reads this on the next
boot, or you can trigger a soft-reset remotely.

Requirements
------------
  pip install pyserial

Usage
-----
  # Show current status
  python display_switch.py --port COM3 --status

  # Switch to I2C display output (4-pin connector)
  python display_switch.py --port COM3 --set i2c

  # Switch to USB-CDC output
  python display_switch.py --port COM3 --set usb

  # Stream to BOTH simultaneously
  python display_switch.py --port COM3 --set both

  # Monitor live frames and print FPS / temperature
  python display_switch.py --port COM3 --monitor

  # Auto-detect port + switch + reset in one step
  python display_switch.py --set i2c --reset

  # Auto-detect port (no --port needed if RP2040 is the only CDC device)
  python display_switch.py --status

Port examples
-------------
  Windows  : COM3, COM4, …
  Linux    : /dev/ttyACM0, /dev/ttyACM1
  macOS    : /dev/tty.usbmodem14201

=============================================================
"""

import argparse
import json
import struct
import sys
import time
from pathlib import Path

try:
    import serial
    import serial.tools.list_ports
except ImportError:
    print("[ERROR] pyserial not installed. Run:  pip install pyserial")
    sys.exit(1)

# ──────────────────────────────────────────────
#  Mode constants — must match main.py
# ──────────────────────────────────────────────
MODE_USB  = 0
MODE_I2C  = 1
MODE_BOTH = 2
MODE_NAMES = {
    MODE_USB:  "USB-CDC",
    MODE_I2C:  "I2C-DISPLAY",
    MODE_BOTH: "BOTH",
}
MODE_KEYS = {
    "usb":  MODE_USB,
    "i2c":  MODE_I2C,
    "both": MODE_BOTH,
    "0":    MODE_USB,
    "1":    MODE_I2C,
    "2":    MODE_BOTH,
}

# ──────────────────────────────────────────────
#  Frame protocol — must match main.py
# ──────────────────────────────────────────────
MAGIC        = 0xDEADBEEF
FRAME_WIDTH  = 32
FRAME_HEIGHT = 24
N_PIXELS     = FRAME_WIDTH * FRAME_HEIGHT
HEADER_FMT   = "<IHHIBxxxii"
HEADER_SIZE  = struct.calcsize(HEADER_FMT)    # 24 bytes
PIXEL_BYTES  = N_PIXELS * 2                   # 1536 bytes
FOOTER_SIZE  = 2
FRAME_SIZE   = HEADER_SIZE + PIXEL_BYTES + FOOTER_SIZE   # 1562 bytes

CONFIG_FILE  = "output_mode.json"


# ══════════════════════════════════════════════
#  Port auto-detection
# ══════════════════════════════════════════════
def find_rp2040_port():
    """Scan serial ports and return the most likely RP2040 CDC port."""
    candidates = []
    for p in serial.tools.list_ports.comports():
        desc = (p.description or "").lower()
        mfr  = (p.manufacturer or "").lower()
        if any(k in desc + mfr for k in
               ("xiao", "rp2040", "raspberry pi", "micropython", "pico", "seeed")):
            candidates.insert(0, p.device)   # prefer exact match at front
        elif "acm" in p.device.lower() or "usbmodem" in p.device.lower():
            candidates.append(p.device)      # generic ACM fallback

    if candidates:
        print(f"[AUTO] Found RP2040 at: {candidates[0]}")
        return candidates[0]
    return None


def open_port(port_name, baud=115200, timeout=2.0):
    try:
        ser = serial.Serial(port_name, baud, timeout=timeout)
        time.sleep(0.1)   # let CDC settle
        return ser
    except serial.SerialException as e:
        print(f"[ERROR] Cannot open {port_name}: {e}")
        sys.exit(1)


# ══════════════════════════════════════════════
#  MicroPython raw REPL helper
# ══════════════════════════════════════════════
class RawREPL:
    """
    Enter/exit MicroPython raw REPL and execute short Python expressions.
    This lets us read/write files on the RP2040 flash from the PC.
    """

    CTRL_C = b'\x03'
    CTRL_D = b'\x04'
    CTRL_E = b'\x05'   # raw REPL mode

    def __init__(self, ser: serial.Serial):
        self.ser = ser

    def _flush(self):
        time.sleep(0.05)
        self.ser.read(self.ser.in_waiting)

    def enter(self):
        """Interrupt running code and enter raw REPL."""
        self.ser.write(self.CTRL_C)
        time.sleep(0.2)
        self.ser.write(self.CTRL_C)
        time.sleep(0.1)
        self._flush()
        self.ser.write(self.CTRL_E)
        time.sleep(0.1)
        resp = self.ser.read(self.ser.in_waiting)
        if b"raw REPL" not in resp and b">" not in resp:
            # Try once more
            self.ser.write(self.CTRL_E)
            time.sleep(0.2)
        self._flush()

    def exit(self):
        """Exit raw REPL, return to normal REPL."""
        self.ser.write(self.CTRL_D)
        time.sleep(0.2)
        self._flush()

    def exec(self, code: str, timeout=5.0) -> str:
        """
        Execute a Python code string in raw REPL.
        Returns stdout output as a string.
        """
        self._flush()
        # Send code + Ctrl-D to execute
        payload = code.encode() + self.CTRL_D
        self.ser.write(payload)

        # Collect response until ">" prompt or timeout
        t0   = time.time()
        buf  = b""
        while time.time() - t0 < timeout:
            chunk = self.ser.read(self.ser.in_waiting or 1)
            if chunk:
                buf += chunk
            if b"\x04>" in buf:   # OK marker
                break
            time.sleep(0.01)

        # Parse: response is  "OK<stdout>\x04<stderr>\x04>"
        try:
            ok_idx = buf.index(b"OK") + 2
            end    = buf.index(b"\x04", ok_idx)
            return buf[ok_idx:end].decode(errors="replace").strip()
        except (ValueError, IndexError):
            return buf.decode(errors="replace").strip()


# ══════════════════════════════════════════════
#  High-level RP2040 operations
# ══════════════════════════════════════════════
def get_current_mode(repl: RawREPL) -> int | None:
    """Read output_mode.json from the RP2040 flash and return mode int."""
    code = f"""
import json
try:
    f = open('{CONFIG_FILE}')
    d = json.load(f)
    f.close()
    print(d.get('mode', -1))
except:
    print(-1)
"""
    result = repl.exec(code.strip())
    try:
        m = int(result.split()[-1])
        return m if m in (MODE_USB, MODE_I2C, MODE_BOTH) else None
    except (ValueError, IndexError):
        return None
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
